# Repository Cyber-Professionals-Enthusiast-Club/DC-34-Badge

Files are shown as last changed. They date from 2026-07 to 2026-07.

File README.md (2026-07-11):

# About
DC-34 Badge contains the KiCad 6 design files for the Cyber Professionals 
Enthusiast Club (CPEC) DEFCON 34 Badge. 

## Board Features
- 2.2" 320x240 display
- Wifi and Bluetooth LE equiped
- 3 Shitty Add On (SAO) 1.69bis ports equiped with I2C
- Gameboy equivalent buttons
- Rumble pack

## Project Structure
The structure of this repo is organized as such:

| Directory | About |
|:---|:---|
| art | SVG files of onboard art |
| DC-34-Badge | KiCad 6 Design files |
| DC-34-Reference-Firmware | Reference firmware, which demonstrates driving hardware devices on board |
| digikey-kicad-libraries  | Symbol libraries and footprints downloaded from digikey |
| kicad-libraries | git subtree containing expressif design files |

## Running
### Board Design
To view schematics, please run KiCad 6.0.11 or later. Change directory into 
DC-34-Badge and run
```
$ kicad DC-34-Badge.kicad_pro &
```

Please note: please run kicad from the same directory as the .kicad_pro file 
is stored because the fp-lib-table and sym-lib-table use relative paths 
so that this project is portable between computers.

### Reference Firmware 
To develop the reference firmware, which demonstrates interfacing with hardware
devices on the board, change directory into DC-34-Reference-Firmware and run:
```
$ arduino-1.8.5 DC-34-Reference-Firmware &
```
Follow the instructions in the comments to set up your development enviroment
for the board. 

Prototype "Rev 1" board should be set up with the configuration in the image below: 

Rev 1 CPEC DC 34 Board showing backwards placed screen and USB dataline inverter

# Associated Repos
Board firmware is developed in this repo: 
[https://github.com/Cyber-Professionals-Enthusiast-Club/DC34-Mech-Badge-Game](https://github.com/Cyber-Professionals-Enthusiast-Club/DC34-Mech-Badge-Game)

# Programming Updates for Rev 2
This board is built on a tight schedule, meaning there is zero margin for 
integrating embeded software with Rev 2. The firmware will need to be integrated 
and tested in hours, preceeding the con before distribution. The following 
tables serves as a guide for new or changed board features for firmware 
development to be conducted before Rev 2 is delivered. 

## What is the same with Rev 1
Most board features on Rev 2 are identical to the Rev 1 prototype board. This
includes:
- Buttons are identical, no buttons have been added or removed. All buttons 
remain on the same GPIO pins
- Display is the same. The display has not changed its pin outs
- SAO ports I2C pins and addresses are the same 

## Board Identifiers
Rev 2, and all mech boards going forward, feature 
*board identification resistors* that board firmware can key in on to determine
what board it is. 

| Identification Bit | GPIO |
|:---|:---|
| 0 | GPIO13 |
| 1 | GPIO15 |
| 2 | GPIO18 |
| 3 | GPIO39 |

These pins are pulled to ground, through a 5.1k ohm resistor, to indicate 0, and 
pulled to 3.3v, through a 5.1k ohm resistor, to indicate 1. 

The board identification bits can be used by firmware, at initial boot up, to
determine what board it is running on. 

This can be configured with the following code:
```
// Declare a global variable to hold the Board ID for use by functions
static volatile uint8_t boardId = 0;

// Set up Identification Bit Pins
pinMode(13, INPUT);
pinMode(15, INPUT);
pinMode(18, INPUT);
pinMode(39, INPUT);

// Get the Board Identification bit values
boardId = 0;
boardId |= (digitalRead(13) & 0x1) << 0;
boardId |= (digitalRead(15) & 0x1) << 1;
boardId |= (digitalRead(18) & 0x1) << 2;
boardId |= (digitalRead(39) & 0x1) << 3;
```

Expect `boardId` to have a value between 0 and 15. The ID for Rev 2 of the 
board, is `0`. Future revs and different versions of the board, will each get 
unique bit values. 

## Rumble Pack
Rev 2 introduces an *enable bit* for the H-Bridge, which drives the motor for
the rumble pack. This was added as a power saving measure. When the board is 
not active, the MOTOR_EN (motor enable) pin should be set to low to prevent the 
motor circuitry from drawing power. This means that there are two GPIO pins 
that drive the rumble pack. 

| Identification Bit | GPIO |
|:---|:---|
| MOTOR_EN | GPIO16 |
| RUMBLE | GPIO17 |

`MOTOR_EN` should be set up as an `OUTPUT` pin with the `pinMode()` function. 
RUMBLE can either be set up as a digital output pin, or as a 
*Pulse Width Modulation* pin to control the motor with different levels. On
the ESP-32, this will let the firmware precisely control the motor to turn it 
at a slower rate than fully on. This can be done with the `ledcAttach()` 
and `ledcWrite()` functions.

`MOTOR_EN` should be set to `LOW` when the user is not actively using the board.

## Output LEDs
The board has six programable LEDs that can be turned on or off. Their qualities
are enumerated in the table below.

| LED Position  | Color  | GPIO |
|:---|:---|:---|
| Right Knee | RED | GPIO12 |
| Left Knee | RED | GPIO45 |
| Right Ear | RED | GPIO40 |
| Left Ear | RED | GPIO41 |
| Right Sholder | RED | GPIO6  |
| Cockpit Light | YELLOW | GPIO42 |

These should be set up as `OUTPUT` pins with the `pinMode()` function. They 
can be turned on or off with the `digitalWrite()` function. Setting the pin
to `HIGH` turns the LED on, setting the pin to `LOW` turns the LED off. 

## Photo Resistor
The Rev 2 board is equiped with a photo resistor to sense light levels. This
can be used to set the screen intensity higher when there is more light. This
resistor is put on `GPIO3`, which can be configured by setting the pin to 
analog read. 

The photo resistor has a maximum resistance of 33kOhms, and is in series with
a 10kohm resistor. At low light levels, it is expected to read a value close 
to 100%, and at high light levels, the pin is expected to read 23%. 

This pin can be used with the `analogRead()` function. 

## Buzzer
The Rev 2 board is equipped with a buzzer to provide sound output. Although 
the Rev 1 board also had a buzzer, its output was too quiet to hear. This 
buzzer is a self contained circuit, and is simpler. The buzzer produces a 
single 3,000 Hz tone, and can be used to indicate something is happening on
the board and that users should direct their attention to it. 

The new buzzer is driven by `GPIO33`. This can be configured as an `OUTPUT` pin 
with the `pinMode()` function. It can be turned on or off with the 
`digitalWrite()` function. Setting the pin to `HIGH` turns the buzzer on, 
setting the pin to `LOW` turns the buzzer off. 

# Bill of Materials (BOM) 
The file, `MechFighters_Badge_BOM_PCBWay_Rev2p0.xlsx` in this git repo contains
the SMD parts list that the board assembler should put on the board. 

The board has throughhole componets that are assembled by the user. The list of 
throughhole componets are listed below, and should be procured for final 
assembly. 

|Part Number | Symbol | Notes | Quantity per Board | Price | Link |
|:---|:---|:---|:---|:---|:-----|
| CFAF240320A0-024SR | DISPLAY | 240x320 Display | 1 | $15.23 | [CrystalFonz](https://www.crystalfontz.com/product/cfaf240320a0024sr-240x320-resistive-touchscreen-tft-display) |
| CPT-1207-5LTH-T | BZ1 | Buzzer | 1 | $0.53 | [Digikey](https://www.digikey.com/en/products/detail/same-sky-formerly-cui-devices/CPT-1207-5LTH-T/29292285) |
| 2011 | BATTERY | Battery | 1 | $12.50 | [Digikey](https://www.digikey.com/en/products/detail/adafruit-industries-llc/2011/6612469)
| VZ4TL2B0370055L | J6 | Haptic Feedback | 1 | $2.63 | [Digikey](https://www.digikey.com/en/products/detail/vybronics-inc/VZ4TL2B0370055L/15220806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) |
| JS202011CQN | SW1 | On/Off Switch | 1 | $0.67 | [Digikey](https://www.digikey.com/en/products/detail/c-k/JS202011CQN/1640097) |
| SFH11-NBPC-D03-ST-BK | J3 - J5 | SAO Connector | 3 | $0.54 | [Digikey](https://www.digikey.com/en/products/detail/sullins-connector-solutions/SFH11-NBPC-D03-ST-BK/4558818) | 
| 1825910-6 | SW2 - SW11 | Button | 10 | $0.09 | [Digikey](https://www.digikey.com/en/products/detail/te-connectivity-alcoswitch-switches/1825910-6/1632536) | 
| S2B-PH-K-S | J7 | Battery Connector | 1 | $0.97 | [Digikey](https://www.digikey.com/en/products/detail/jst-sales-america-inc/S2B-PH-K-S/926626) | 
| PDV-P8103 | R31 | Photo Resistor | 1 | $0.61 | [Digikey](https://www.digikey.com/en/products/detail/advanced-photonix/PDV-P8103/480610) |

# Media
## Board Schematics 
Rev 2 Schematic with ESP-32-S3

## 3D Renders

### Board Front View
Rev 2 Board Front View

### Board Back View
Rev 2 Board Back View

### Panelized Board Front View
Rev 2 Panelized Board Front View

### Panelized Board Back View
Rev 2 Panelized Board Back View

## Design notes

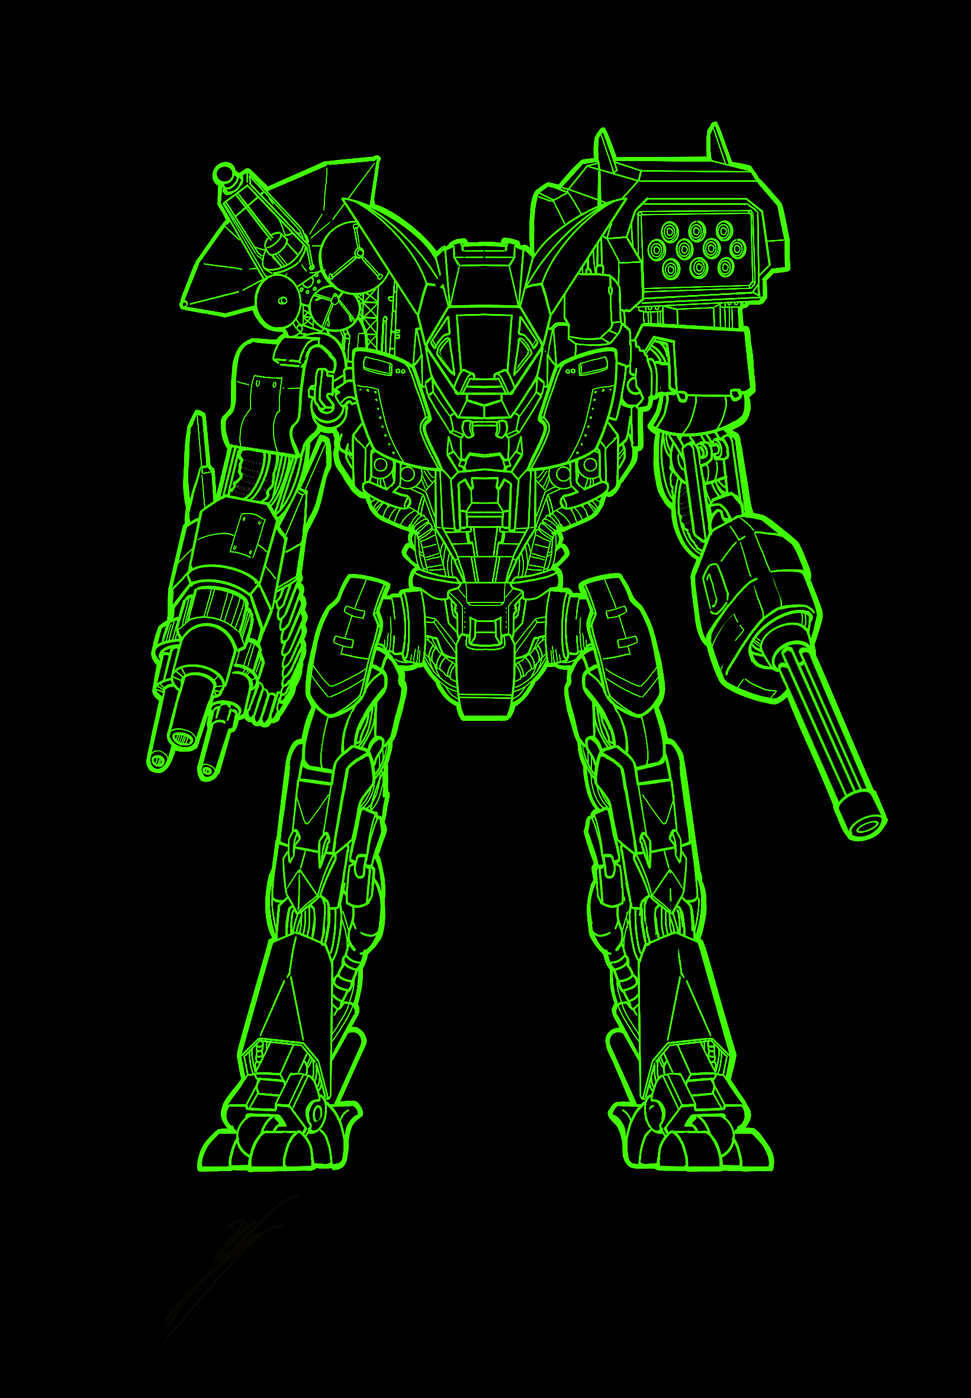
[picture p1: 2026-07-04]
art/cd32_beta_mech_art_flatcoloronly.png

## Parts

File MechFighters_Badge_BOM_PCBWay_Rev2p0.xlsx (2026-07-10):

 |  |  | CPEC Mechfighters Badge Rev 2, 69PCS BOM (Bill of Materials)
Item # | *Designator | *Qty | Manufacturer | *Mfg Part # | Description / Value | *Package/Footprint | Type | Your Instructions / Notes
1 | D1 | 1 | MCC (Micro Commercial Components) | MBR0540 | DIODE SCHOTTKY 40V 500MA SOD123 | SOD-123 | SMD
2 | D2 | 1 | Lite-On Inc. | LTST-C190KSKT | LED YELLOW CLEAR CHIP SMD | 0603 (1608 Metric) | SMD
3 | D3, D4, D5, D6, D7 | 5 | Lite-On Inc. | LTST-C190KRKT | LED RED CLEAR CHIP SMD | 0603 (1608 Metric) | SMD
4 | D8 | 1 | Würth Elektronik | 155124YS73200 | LED YELLOW CLEAR 1204 SMD R/A | 2-SMD, Side View | SMD
5 | Q1 | 1 | Diodes Incorporated | DMG3415U-7 | MOSFET P-CH 20V 4A SOT23-3 | SOT-23-3 | SMD
6 | J1 | 1 | Same Sky | UJ20-C-H-G-SMT-5-P16-TR | USB-C (USB TYPE-C) |  | SMD
7 | J2 | 1 | Amphenol ICC (FCI) | 62684-402100ALF | CONN FPC TOP 40POS 0.5MM R/A |  | SMD
8 | U1 | 1 | Espressif Systems | ESP32-S3-MINI-1-N8 | RF TXRX MOD BT WIFI PCB TH SMD | 41-SMD Module | SMD
9 | U2 | 1 | Diodes Incorporated | AP2112K-3.3TRG1 | IC REG LINEAR 3.3V 600MA SOT-25 | SOT-25 | SMD
10 | U3 | 1 | Analog Devices Inc./Maxim Integrated | MAX17048G_T10 | IC BATT MON LI-ION 1CELL 8TDFN | 8-TDFN-EP (2x2) | SMD
11 | U4 | 1 | Microchip Technology | MCP73831T-2ACI/OT | IC BATT CNTL LI-ION 1CEL SOT23-5 | SOT-23-5 | SMD
12 | U5 | 1 | Diodes Incorporated | AP3036BKTR-G1 | IC LED DRVR RGLTR PWM SOT23-6 | SOT-23-6 | SMD
13 | U6 | 1 | 3PEAK | TPM8837E-DF4R | H-BRIDGE DRIVER 17V 1A 8-DFN | 8-WFDFN Exposed Pad | SMD
14 | L1 | 1 | Taiyo Yuden | CBC3225T220MR | 22 uH | 1210 | SMD
16 | R1 | 1 | Panasonic Electronic Components | ERJ-2GEJ5R1X | 5.1 ohms | 0402 | SMD
17 | R2 | 1 | YAGEO | RC0402FR-071ML | 1 M | 0402 | SMD
18 | R3, R4 | 2 | YAGEO | RC0402FR-07100KL | 100 k | 0402 | SMD
19 | R5, R6, R7 | 3 | Stackpole Electronics Inc | RMCF0402FT10K0 | 10 k | 0402 | SMD
20 | R8, R9, R10, R11, R12, R13, R14, R15, R16, R17, R18, R19, R20, R21, R22, R23, R24, R25, R26, R27, R28, R29, R30 | 23 | YAGEO | RC0402FR-075K1L | 5.1 k | 0402 | SMD
21 | C1, C2, C3, C4, C5, C6, C7, C8, | 8 | Murata Electronics | GRM155R61A106ME11D | 10 uF | 0402 | SMD
22 | C9, C10, C11, C12, C13, C14, C15, C16, C17, C18, C19, C20, | 12 | KEMET | C0402C105K9PACTU | 1 uF | 0402 | SMD
23 | C21 | 1 | Walsin | 0402B104K160CT | 0.1 uF | 0402 | SMD
24 | J3, J4, J5, J6, J7 | 0 |  |  | DNP (Do not Populate) |  | THT
25 | SW1 | 0 |  |  | DNP (Do not Populate) |  | THT
26 | SW2, SW3, SW4, SW5, SW6, SW7, SW8, SW9, SW10, SW11 | 0 |  |  | DNP (Do not Populate) |  | THT
27 | BZ1 | 0 |  |  | DNP (Do not Populate) |  | THT
28 | R31 | 0 |  |  | DNP (Do not Populate) |  | THT
 |  | 69

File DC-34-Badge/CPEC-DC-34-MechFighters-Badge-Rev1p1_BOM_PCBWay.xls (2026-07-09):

CPEC DC-34 Mechfighters Badge Rev 1.1, 84PCS BOM (Bill of Materials)
Item # | *Designator | *Qty | Manufacturer | *Mfg Part # | Description / Value | *Package/Footprint | Mounting Type
1 | D1 | 1 | MCC (Micro Commercial Components) | MBR0540 | DIODE SCHOTTKY 40V 500MA SOD123 | SOD-123 | SMD
2 | D2, D3, D4, D5, D6, D7, D8 | 7 | Lite-On Inc. | LTST-C190KSKT | LED YELLOW CLEAR CHIP SMD | 0603 (1608 Metric) | SMD
3 | D9, D10, D11, D12, D13, D14 | 6 | Lite-On Inc. | LTST-C190KRKT | LED RED CLEAR CHIP SMD | 0603 (1608 Metric) | SMD
4 | Q1 | 1 | Shenzhen Slkormicro Semicon Co., Ltd. | C1815 | 50V 200MW 130@2MA,6V 150MA NPN S | SOT-23 | SMD
5 | Q2 | 1 | Diodes Incorporated | DMG3415U-7 | MOSFET P-CH 20V 4A SOT23-3 | SOT-23-3 | SMD
6 | J1 | 1 | Hirose Electric Co Ltd | CX90B-16P1 | USB-C (USB TYPE-C) |  | SMD
7 | J2 | 1 | Amphenol ICC (FCI) | 62684-402100ALF | CONN FPC TOP 40POS 0.5MM R/A |  | SMD
8 | U1 | 1 | Espressif Systems | ESP32-S3-MINI-1-N8 | RF TXRX MOD BT WIFI PCB TH SMD | 41-SMD Module | SMD
9 | U2 | 1 | Diodes Incorporated | AP2112K-3.3TRG1 | IC REG LINEAR 3.3V 600MA SOT-25 | SOT-25 | SMD
10 | U3 | 1 | Analog Devices Inc./Maxim Integrated | MAX17048G_T10 | IC BATT MON LI-ION 1CELL 8TDFN | 8-TDFN-EP (2x2) | SMD
11 | U4 | 1 | Microchip Technology | MCP73831T-2ACI/OT | IC BATT CNTL LI-ION 1CEL SOT23-5 | SOT-23-5 | SMD
12 | U5 | 1 | Diodes Incorporated | AP3036BKTR-G1 | IC LED DRVR RGLTR PWM SOT23-6 | SOT-23-6 | SMD
13 | U6 | 1 | 3PEAK | TPM8837E-DF4R | H-BRIDGE DRIVER 17V 1A 8-DFN | 8-WFDFN Exposed Pad | SMD
14 | L1 | 1 | Taiyo Yuden | CBC3225T220MR | 22 uH | 1210 | SMD
15 | SW1 | 0 |  |  | DNP (Do Not Populate)
16 | R1 | 1 | Panasonic Electronic Components | ERJ-2GEJ5R1X | 5.1 ohms | 0402 | SMD
17 | R2 | 1 | YAGEO | RC0402FR-071ML | 1 M | 0402 | SMD
18 | R3, R4 | 2 | YAGEO | RC0402FR-07100KL | 100 k | 0402 | SMD
19 | R5, R6, R7, R8 | 4 | Stackpole Electronics Inc | RMCF0402FT10K0 | 10 k | 0402 | SMD
20 | R9, R10, R11, R12, R13, R14, R15, R16, R17, R18, R19, R20, R21, R22, R23, R24, R25, R26, R27, R28, R31, R32, R33, R34, R35, R36, R37 | 27 | YAGEO | RC0402FR-075K1L | 5.1 k | 0402 | SMD
21 | R29, R30 | 2 | YAGEO | RC0402FR-071KL | 1 k | 0402 | SMD
22 | C1, C2, C3, C4, C5, C6, C7, C8 | 8 | Murata Electronics | GRM155R61A106ME11D | 10 uF | 0402 | SMD
23 | C9, C10, C11, C12, C13, C14, C15, C16, C17, C18, C19, C20 | 12 | KEMET | C0402C105K9PACTU | 1 uF | 0402 | SMD
24 | C21 | 1 | Walsin | 0402B104K160CT | 0.1 uF | 0402 | SMD
25 | J3, J4, J5, J6, J7 | 0 |  |  | DNP (Do Not Populate)
26 | SW1, SW2, SW3, SW4, SW5, SW6, SW7, SW8, SW9, SW10, SW11, SW12 | 0 |  |  | DNP (Do Not Populate)
27 | BZ1 | 0 |  |  | DNP (Do Not Populate)
28 | R38 | 0 |  |  | DNP (Do Not Populate)

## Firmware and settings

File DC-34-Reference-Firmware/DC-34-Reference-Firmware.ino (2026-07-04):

/** DC-34 Reference Firmware demonstrates how to drive the hardware on the
 *  CPEC DEFCON 34 Mech Fighter's badge. 
 * 
 * Developers should program their Arduino IDE to progam for the ESP32-S3-MINI-1
 * 
 * @author Ministry
 * @version 06 June 2026
 */

// Code is built for the Arduino IDE 1.8.5
// In the Arduino IDE Install these additional board managers 
// https://raw.githubusercontent.com/espressif/arduino-esp32/gh-pages/package_esp32_index.json
// File > Preferences (then paste into Additional Board Manager URLs)
// 
// Then, before verifying, install the following libraries:
// Sketch > Include Library > Manage Libraries... 
// - Adafruit seesaw Library
// - Adafruit BusIO 
// - Adafruit ST7735 and ST7789 Library
// - Adafruit GFX Library 
// - Adafruit ILI9341
// - Adafruit MAX1704X
// 
// Before uploading, select the following
// Tools > Board: "Adafruit Feather ESP32-S3 No PSRAM"
// 

#include <Arduino.h>
#include <SPI.h>
#include <Adafruit_GFX.h>
#include <Adafruit_ILI9341.h>
#include "Query-SAO.h"

// Set I2C bus to use: Wire, Wire1, etc.
#define WIRE Wire

//#define DEBUG_ENABLE 0

/* Const values (wont change */
// Allocated on the .text section

// This definition maps the LEDs to their respective IO Pins 
const uint16_t LED_TORSO_YELLOW     = 3;
const uint16_t LED_TORSO_RED        = 6;
const uint16_t LED_ARM_LEFT_RED     = 12;
const uint16_t LED_ARM_LEFT_YELLOW  = 13;
const uint16_t LED_HEAD_YELLOW      = 15;
const uint16_t LED_HEAD_RED         = 16;
const uint16_t LED_LEG_RIGHT_YELLOW = 39;
const uint16_t LED_LEG_RIGHT_RED    = 40;
const uint16_t LED_LEG_LEFT_RED     = 41;
const uint16_t LED_LEG_LEFT_YELLOW  = 42;
const uint16_t LED_ARM_RIGHT_RED    = 45;
const uint16_t LED_ARM_RIGHT_YELLOW = 46;
const uint16_t BUZZER_OUT = 33;

// Pin definitions (match wiring)
const uint16_t  TFT_SCLK = 36;
const uint16_t  TFT_MISO = 37;
const uint16_t  TFT_MOSI = 35;
const uint16_t  TFT_DC   = 26; // WRB
const uint16_t  TFT_CS   = 38;
const uint16_t  TFT_RST  = 21;

// This definition maps the buttons to pins 
const uint16_t BUTTON_SELECT = 1;
const uint16_t BUTTON_START = 2;
const uint16_t BUTTON_UP = 7;
const uint16_t BUTTON_LEFT = 8;
const uint16_t BUTTON_RIGHT = 9;
const uint16_t BUTTON_DOWN = 10;
const uint16_t BUTTON_A = 11;
const uint16_t BUTTON_B = 14;

// PWM Pins
const uint8_t PWM_RUMBLE = 17;
const uint8_t PWM_BACKLIGHT = 47;

Adafruit_ILI9341 tft = Adafruit_ILI9341(TFT_CS, TFT_DC,
      TFT_MOSI, TFT_SCLK, TFT_RST, -1);

/* Variables that will change: */
// Allocated in .bss section 
int ledState = LOW;             // ledState used to set the LED

// Generally, you should use "unsigned long" for variables that hold time
// The value will quickly become too large for an int to store
unsigned long previousMillis = 0;        // will store last time LED was updated
unsigned long previousSaoMillis = 0;

int RUMBLE_DUTY = 0;
int BACKLIGHT_DUTY = 128;

// constants won't change:
const long interval = 1000;           // interval at which to blink LES (milliseconds)
const long saoInterval = 1333;        // Interval to check SAO boards 

const uint32_t PWM_FREQ_BACKLIGHT = 20000; // 20 kHz 
const uint32_t PWM_FREQ_RUMBLE = 20000; // 20 kHz 
const uint8_t  PWM_RESOLUTION = 8; 

/* Function Calls */

// This interrupt triggers when a button is pressed 
void ARDUINO_ISR_ATTR buttonISR () {
    #ifdef DEBUG_ENABLE 
        Serial.print("Button Interrupt Triggered: ");
    #endif 
  
    static unsigned long lastUpDownButtonPress;
    static unsigned long lastAButtonPress;
    static unsigned long lastBButtonPress;
    int upState = digitalRead(BUTTON_UP);
    int downState = digitalRead(BUTTON_DOWN);
    int aState = digitalRead(BUTTON_A);
    int bState = digitalRead(BUTTON_B);

    #ifdef DEBUG_ENABLE 
        Serial.print(upState);
        Serial.print(" ");
        Serial.print(downState);
        Serial.print(" ");
        Serial.print(aState);
        Serial.print(" ");
        Serial.print(bState);
        Serial.println(" ");
    #endif 

    unsigned long currentButtonPressTime = millis();
    // Scale up or down the intensity of the backlight 
    
    if ( upState != downState)
    {
        // Last button Press
        unsigned long currentUpDownButtonPress = millis();
        if (currentUpDownButtonPress - lastUpDownButtonPress > 10)
        {
            if (upState == HIGH) {
                if (BACKLIGHT_DUTY < 256)
                {
                    BACKLIGHT_DUTY += 1;
                }
            }
            else {
                if (BACKLIGHT_DUTY > 0)
                {
                    BACKLIGHT_DUTY -= 1;
                }
            }
            ledcWrite(PWM_BACKLIGHT, BACKLIGHT_DUTY);
        }
        lastUpDownButtonPress = millis();
    }

    
    // Active Low, so when A is low it is high
    if ( aState == LOW )
    {
        if(currentButtonPressTime - lastAButtonPress > 20)
        {
            if (RUMBLE_DUTY < 256)
            {
                RUMBLE_DUTY += 1;
            }
            digitalWrite(LED_LEG_LEFT_RED, HIGH);
            digitalWrite(LED_LEG_LEFT_YELLOW, HIGH);
        }

        lastAButtonPress = millis();
    }
    else
    {
        if(currentButtonPressTime - lastAButtonPress > 20)
        {
            /*
            RUMBLE_DUTY = 0;
            digitalWrite(LED_LEG_LEFT_RED, LOW);
            digitalWrite(LED_LEG_LEFT_YELLOW, LOW);
            lastAButtonPress = millis();
            */
            digitalWrite(LED_LEG_LEFT_RED, LOW);
            digitalWrite(LED_LEG_LEFT_YELLOW, LOW);
        }
    }
    //ledcWrite(PWM_RUMBLE, RUMBLE_DUTY);

    // Active Low, so when B is low it is high
    if ( bState == LOW )
    {
        if(currentButtonPressTime - lastBButtonPress > 20)
        {
            digitalWrite(PWM_RUMBLE, HIGH);
            digitalWrite(LED_LEG_RIGHT_YELLOW, HIGH);
            digitalWrite(LED_LEG_RIGHT_RED, HIGH);
            lastBButtonPress = millis();
        }
    }
    else
    {
        if(currentButtonPressTime - lastBButtonPress > 20)
        {
            digitalWrite(PWM_RUMBLE, LOW);
            digitalWrite(LED_LEG_RIGHT_YELLOW, LOW);
            digitalWrite(LED_LEG_RIGHT_RED, LOW);
            lastBButtonPress = millis();
        }
    }
}

void setup() {
    #ifdef DEBUG_ENABLE 
        Serial.begin(9600);
        while (!Serial)
            delay(10);
        Serial.println("\nDC 34 Reference Firmware");
    #endif 
    
    // put your setup code here, to run once:
    pinMode(LED_TORSO_YELLOW, OUTPUT);
    pinMode(LED_TORSO_RED, OUTPUT);
    pinMode(LED_ARM_LEFT_RED, OUTPUT);
    pinMode(LED_ARM_LEFT_YELLOW, OUTPUT);
    pinMode(LED_HEAD_YELLOW, OUTPUT);
    pinMode(LED_HEAD_RED, OUTPUT);
    pinMode(LED_LEG_RIGHT_YELLOW, OUTPUT);
    pinMode(LED_LEG_RIGHT_RED, OUTPUT);
    pinMode(LED_LEG_LEFT_RED, OUTPUT);
    pinMode(LED_LEG_LEFT_YELLOW, OUTPUT);
    pinMode(LED_ARM_RIGHT_RED, OUTPUT);
    //pinMode(LED_ARM_RIGHT_YELLOW, OUTPUT); 
    pinMode(BUZZER_OUT, OUTPUT);
    //pinMode(PWM_BACKLIGHT, OUTPUT);

    pinMode(BUTTON_SELECT, INPUT_PULLUP);
    pinMode(BUTTON_START, INPUT_PULLUP);
    pinMode(BUTTON_UP, INPUT_PULLUP);
    pinMode(BUTTON_LEFT, INPUT_PULLUP);
    pinMode(BUTTON_RIGHT, INPUT_PULLUP);
    pinMode(BUTTON_DOWN, INPUT_PULLUP);
    pinMode(BUTTON_A, INPUT_PULLUP);
    pinMode(BUTTON_B, INPUT_PULLUP);

    attachInterrupt(BUTTON_SELECT, buttonISR, CHANGE);
    attachInterrupt(BUTTON_START, buttonISR, CHANGE);
    attachInterrupt(BUTTON_UP, buttonISR, CHANGE);
    attachInterrupt(BUTTON_LEFT, buttonISR, CHANGE);
    attachInterrupt(BUTTON_RIGHT, buttonISR, CHANGE);
    attachInterrupt(BUTTON_DOWN, buttonISR, CHANGE);
    attachInterrupt(BUTTON_A, buttonISR, CHANGE);
    attachInterrupt(BUTTON_B, buttonISR, CHANGE);
    
    //bool pwmRumbleAttachSuccess = ledcAttach(PWM_RUMBLE, PWM_FREQ_RUMBLE, PWM_RESOLUTION);
    bool pwmBackightAttachSuccess = ledcAttach(PWM_BACKLIGHT, PWM_FREQ_BACKLIGHT, PWM_RESOLUTION);
    pinMode(PWM_RUMBLE, OUTPUT);
    //digitalWrite(PWM_BACKLIGHT, HIGH);
    ledcAttach(LED_ARM_RIGHT_YELLOW, PWM_FREQ_BACKLIGHT, PWM_RESOLUTION);

    #ifdef DEBUG_ENABLE 
        if (pwmRumbleAttachSuccess) {
            Serial.println("Rumble PWM attach success");
        } 
        else {
            Serial.println("Rumble PWM attach not successful");
        }
        if (pwmBackightAttachSuccess) {
            Serial.println("Backlight PWM attach success");
        } 
        else {
            Serial.println("Backlight PWM attach not successful");
        }
    #endif 
    
    //bool pwmRumbleWriteSuccess = ledcWrite(PWM_RUMBLE, RUMBLE_DUTY);
    bool pwmBackightWriteSuccess = ledcWrite(PWM_BACKLIGHT, BACKLIGHT_DUTY);
    ledcWrite(LED_ARM_RIGHT_YELLOW, 0);

    #ifdef DEBUG_ENABLE 
        if (pwmRumbleWriteSuccess) {
            Serial.println("Rumble PWM write success");
        } 
        else {
            Serial.println("Rumble PWM write not successful");
        }
        if (pwmBackightWriteSuccess) {
            Serial.println("Backlight PWM write success");
        } 
        else {
            Serial.println("Backlight PWM write not successful");
        }
    #endif 

    tft.begin();

    tft.setRotation(1); // Landscape
    tft.fillScreen(ILI9341_BLACK);

    tft.setTextColor(ILI9341_WHITE);
    tft.setTextSize(1);
    tft.setCursor(40, 120);

    tft.println("Hello World!");
}

void loop() {
    unsigned long currentMillis = millis();
    query_sao_collection_t saoResponse;
    
    if (currentMillis - previousMillis >= interval) {
        // save the last time you blinked the LED
        previousMillis = currentMillis;

        // if the LED is off turn it on and vice-versa:
        if (ledState == LOW) {
            ledState = HIGH;
        } else {
            ledState = LOW;
        }

        digitalWrite(LED_TORSO_YELLOW, ledState);
        digitalWrite(LED_TORSO_RED, ledState);
        digitalWrite(LED_ARM_LEFT_RED, ledState);
        digitalWrite(LED_ARM_LEFT_YELLOW, ledState);
        digitalWrite(LED_HEAD_YELLOW, ledState);
        digitalWrite(LED_HEAD_RED, ledState);
        digitalWrite(LED_ARM_RIGHT_RED, ledState);
        //digitalWrite(LED_ARM_RIGHT_YELLOW, ledState); 
        //digitalWrite(BUZZER_OUT, ledState);

        if (ledState == HIGH)
        {
            ledcFade(LED_ARM_RIGHT_YELLOW, 0, 255, 500);
        }
        else
        {
            ledcFade(LED_ARM_RIGHT_YELLOW, 255, 0, 500);
        }


    }
    // Query SAOs and write to the screen 
    if (currentMillis - previousSaoMillis >= saoInterval) {
        saoResponse = query_sao();
        tft.fillScreen(ILI9341_BLACK);
        tft.setTextSize(1);
        tft.setCursor(40, 120);
        tft.println("Hello World!");
        tft.setCursor(10, 10);
        tft.println(sao_return_to_string(saoResponse.SAO0));
        tft.setCursor(10, 30);
        tft.println(sao_return_to_string(saoResponse.SAO1));
        tft.setCursor(10, 50);
        tft.println(sao_return_to_string(saoResponse.SAO2));
        tft.setCursor(10, 70);
        tft.print("Battery ID: ");
        tft.println(saoResponse.chipID, HEX);
        tft.setCursor(10, 90);
        tft.print("Battery Level: ");
        tft.println(saoResponse.battery_percentage);

        previousSaoMillis = millis();
    }

    //buttonISR();
}

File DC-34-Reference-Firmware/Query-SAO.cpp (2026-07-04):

#include "Query-SAO.h" 
#include <Wire.h>
#include <Adafruit_MAX1704X.h>
#include "Adafruit_seesaw.h"

query_sao_collection_t query_sao(void)
{
    const int sda_pin = 4;
    const int scl_pin = 5;
  
    query_sao_collection_t returnVal = {QUERY_SAO_NONE, QUERY_SAO_NONE, QUERY_SAO_NONE, 0};
    Adafruit_seesaw sao0;
    Adafruit_seesaw sao1; 
    Adafruit_seesaw sao2;
    Adafruit_MAX17048 maxlipo;
    uint32_t pinRead = 0x3F;
    byte error;
     
    int address = 0x49;

    WIRE.setPins(sda_pin, scl_pin);
    WIRE.begin();

    // Get cell voltage
    maxlipo.begin(&WIRE);
    returnVal.chipID = maxlipo.getChipID();
    maxlipo.cellPercent();
    
    //WIRE.setClock(10000);
    WIRE.beginTransmission(address);
    error = WIRE.endTransmission();
    if (error == 0)
    {
        if(sao0.begin(address))
        {
            sao0.pinModeBulk(pinRead, INPUT);
            sao0.pinMode(10, OUTPUT);
            uint32_t pinStatus = sao0.digitalReadBulk(pinRead);
            returnVal.SAO0 = (query_sao_return_t)(pinStatus + 1);
            sao0.digitalWrite(10, LOW);
        }
    }
    address += 1;
    WIRE.beginTransmission(address);
    error = WIRE.endTransmission();
    if (error == 0)
    {
        if(sao1.begin(address))
        {
            sao1.pinModeBulk(pinRead, INPUT);
            sao1.pinMode(10, OUTPUT);
            uint32_t pinStatus = sao1.digitalReadBulk(pinRead);
            returnVal.SAO1 = (query_sao_return_t)(pinStatus + 1);
            sao1.digitalWrite(10, LOW);
        }
    }
    address += 1;
    WIRE.beginTransmission(address);
    error = WIRE.endTransmission();
    if (error == 0)
    {
        if(sao2.begin(address))
        {
            sao2.pinModeBulk(pinRead, INPUT);
            sao2.pinMode(10, OUTPUT);
            uint32_t pinStatus = sao2.digitalReadBulk(pinRead);
            returnVal.SAO2 = (query_sao_return_t)(pinStatus + 1);
            sao2.digitalWrite(10, LOW);
        }
    }

    
    returnVal.battery_percentage = maxlipo.cellPercent();
    return returnVal;
}

char * sao_return_to_string(query_sao_return_t returnType)
{
    switch(returnType)
    {
        case QUERY_SAO_NONE: return "no sao plugged in";
        case QUERY_SAO_MISSILE_LAUNCHER: return "missile launcher";
        case QUERY_SAO_GATLING_GUN: return "gatling gun";
        case QUERY_SAO_LASER_CANNON: return "laser cannon";
        default: return "unidentified device";
    }
}

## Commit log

2026-04-26 Updated badge schematic to match fritzing schematic on DC-34-Display.
    [DC-34-Badge.kicad_sch]
2026-05-02 Replaced componet not in stock. Added impedence matched USB trace.
    [DC-34-Badge.kicad_pcb, DC-34-Badge.kicad_sch]
2026-05-03 Added silkscreen file.
2026-05-03 Removed errors from design.
    [DC-34-Badge.kicad_pcb, DC-34-Badge.kicad_sch]
2026-05-03 Added LEDs to schematic.
    [DC-34-Badge.kicad_sch]
2026-05-03 Changed resistor name for photo resistor.
    [DC-34-Badge.kicad_sch]
2026-05-03 Added missing connection
    [DC-34-Badge.kicad_pcb, DC-34-Badge.kicad_sch]
2026-05-04 Achieved rough placement.
    [DC-34-Badge.kicad_pcb, DC-34-Badge.kicad_sch]
2026-05-04 Completed Place and Route.
    [DC-34-Badge.kicad_pcb, DC-34-Badge.kicad_sch]
2026-05-04 Added BOM.
    [MechFighters_Badge_BOM_PCBWay.xlsx]
2026-06-07 LEDs light up and respond to button presses.
2026-06-15 Got SAO plugin working and enabled protocol led light.
2026-06-17 Fixed USB direction on Schematic.
    [DC-34-Badge.kicad_sch]
2026-06-17 Updated 40-pin ZIF connector to match Crystal Fonz display orientation.
2026-06-17 Updated version to 2.0 on Schematic.
    [DC-34-Badge.kicad_sch]
2026-06-17 Updated footprint for 40-pin ZIF connector in PCB file.
    [DC-34-Badge.kicad_pcb]
2026-06-17 Added schematic screenshot to README file.
2026-06-30 Updated board with new USB and changed 40 pin connector location. Need to reconnect leads on PCB Editor
    [DC-34-Badge.kicad_pcb, DC-34-Badge.kicad_sch, MechFighters_Badge_BOM_PCBWay.xlsx]
2026-07-01 Flipped LED positions, names, added back display silksaw.
    [DC-34-Badge.kicad_pcb, DC-34-Badge.kicad_sch, MechFighters_Badge_BOM_PCBWay.xlsx]
2026-07-02 Made updates to wiring.
    [DC-34-Badge.kicad_pcb]
2026-07-02 Went back to through hole buttons.
    [DC-34-Badge.kicad_pcb, DC-34-Badge.kicad_sch]
2026-07-02 Updates to H-Bridge design.
    [DC-34-Badge.kicad_pcb, DC-34-Badge.kicad_sch, MechFighters_Badge_BOM_PCBWay.xlsx]
2026-07-04 Attempt to get battery working.
2026-07-04 Brought size of cd32_beta_mech_art_flatcoloronly.svg to fit on existing board.
2026-07-05 Added Sideview LED, imported latest art.
    [DC-34-Badge.kicad_pcb, DC-34-Badge.kicad_sch]
2026-07-05 Added sideview LED to BOM.
    [MechFighters_Badge_BOM_PCBWay.xlsx]
2026-07-05 Converted to a buzzer that does not need a driver circuit.
    [DC-34-Badge.kicad_sch]
2026-07-05 Hooked up enable pin for motow H-Bridge.
    [DC-34-Badge.kicad_pcb, DC-34-Badge.kicad_sch]
2026-07-05 Updated IO.
    [DC-34-Badge.kicad_pcb, DC-34-Badge.kicad_sch]
2026-07-06 Updates to BOM.
    [MechFighters_Badge_BOM_PCBWay.xlsx]
2026-07-07 Added developer names.
    [DC-34-Badge.kicad_pcb]
2026-07-07 Moved over preforated cutouts on board.
2026-07-07 Removed extra shapes from silkscreen isolation.
2026-07-07 Put all art into KiCad.
    [DC-34-Badge.kicad_pcb]
2026-07-07 Moved silkscreen text.
    [DC-34-Badge.kicad_pcb]
2026-07-08 Updated Mech
    Place and route in progress.
    [DC-34-Badge.kicad_pcb, DC-34-Badge.kicad_sch, MechFighters_Badge_BOM_PCBWay.xlsx]
2026-07-09 Did place annd route.
    [DC-34-Badge.kicad_pcb, DC-34-Badge.kicad_sch]
2026-07-09 Ran DRC, fixxed errors and warning, all remaining errors are on the manufacturer provided footprint.
    [DC-34-Badge.kicad_pcb]
2026-07-09 Made adjustments to silkscreen, resolved a few more design rule check warnings.
    [DC-34-Badge.kicad_pcb, MechFighters_Badge_BOM_PCBWay.xlsx]
2026-07-09 Exposed copper layers beneath solder mask.
    [DC-34-Badge.kicad_pcb]
2026-07-09 Added fiducial marks.
    [DC-34-Badge.kicad_pcb]
2026-07-09 Aligned all componet numbers to have no gaps in numbering. Added minus signes to diodes.
    [CPEC-DC-34-MechFighters-Badge-Rev1p1_BOM_PCBWay.xls, DC-34-Badge.kicad_pcb, DC-34-Badge.kicad_sch]
2026-07-09 Added orientation cues for all diodes and ICs.
    [DC-34-Badge.kicad_pcb]
2026-07-10 Updates to the BOM, set correct number of resistors for Item 20.
    [MechFighters_Badge_BOM_PCBWay.xlsx, MechFighters_Badge_BOM_PCBWay_Rev2p0.xlsx]
2026-07-10 Board updates.
    [DC-34-Badge.kicad_sch]
2026-07-10 Updated images on board.
2026-07-10 Added projeojects for panels.
    [DC-34-Badge-panel.kicad_pcb]
2026-07-11 Updated schematic to document board registration pins.
    [DC-34-Badge.kicad_sch]
2026-07-11 Updated README, added Programming Updates for Rev 2, and Bill of Materials Section.
